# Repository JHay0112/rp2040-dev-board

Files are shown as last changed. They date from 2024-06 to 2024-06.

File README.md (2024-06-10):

# RP2040 Dev. Board

This repository contains a development board design for the RP2040 loosely 
based around the Pi Pico. 

The goal of this design was to produce a development board for a common 
microcontroller for the purpose of demonstrating a simple PCB design. The 
design had to be breadboard compatible and use USB-C for programming. 

The designed board (as shown below) fulfills all of these requirements.

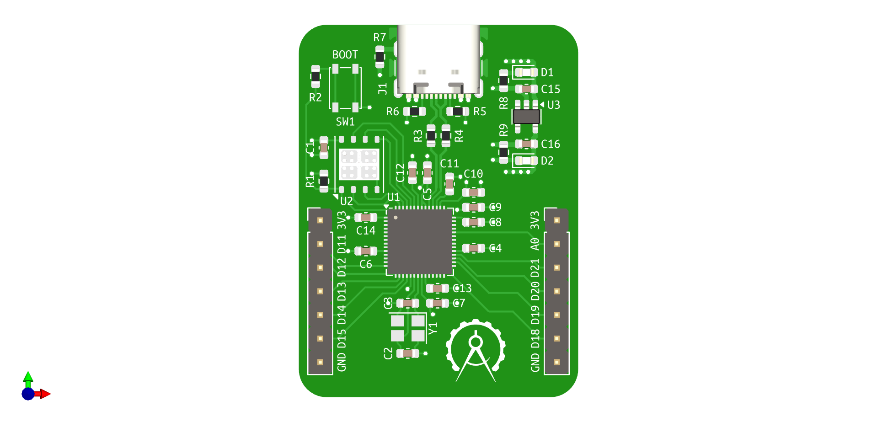
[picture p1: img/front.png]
Front View


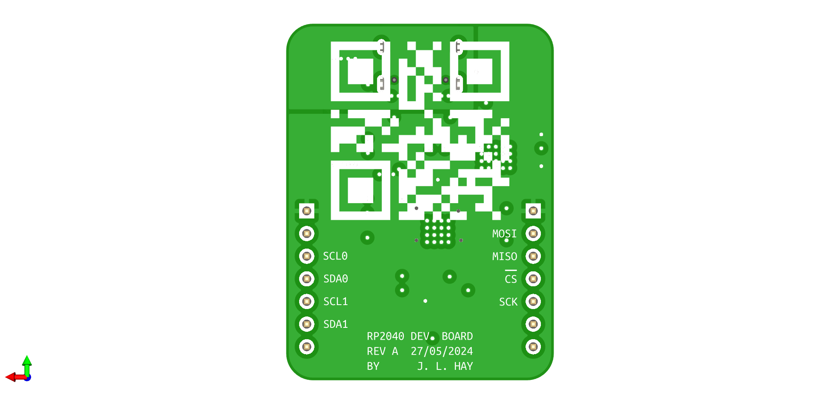
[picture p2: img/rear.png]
Rear View


The board was manufactured and assembled by JLCPCB, and used to blink an LED
to demonstrate it is in working condition (shown below).

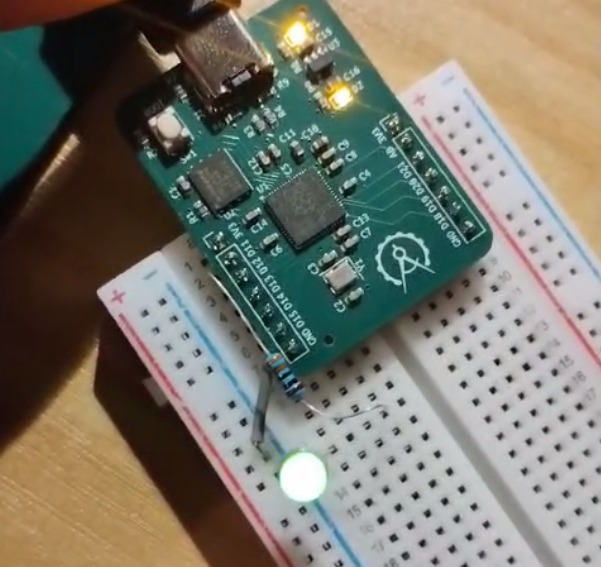
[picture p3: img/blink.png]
LED Blinking


The design of the board could be improved by increasing pin count and 
reducing the width of the PCB to allow more room for breadboarding around
the board.

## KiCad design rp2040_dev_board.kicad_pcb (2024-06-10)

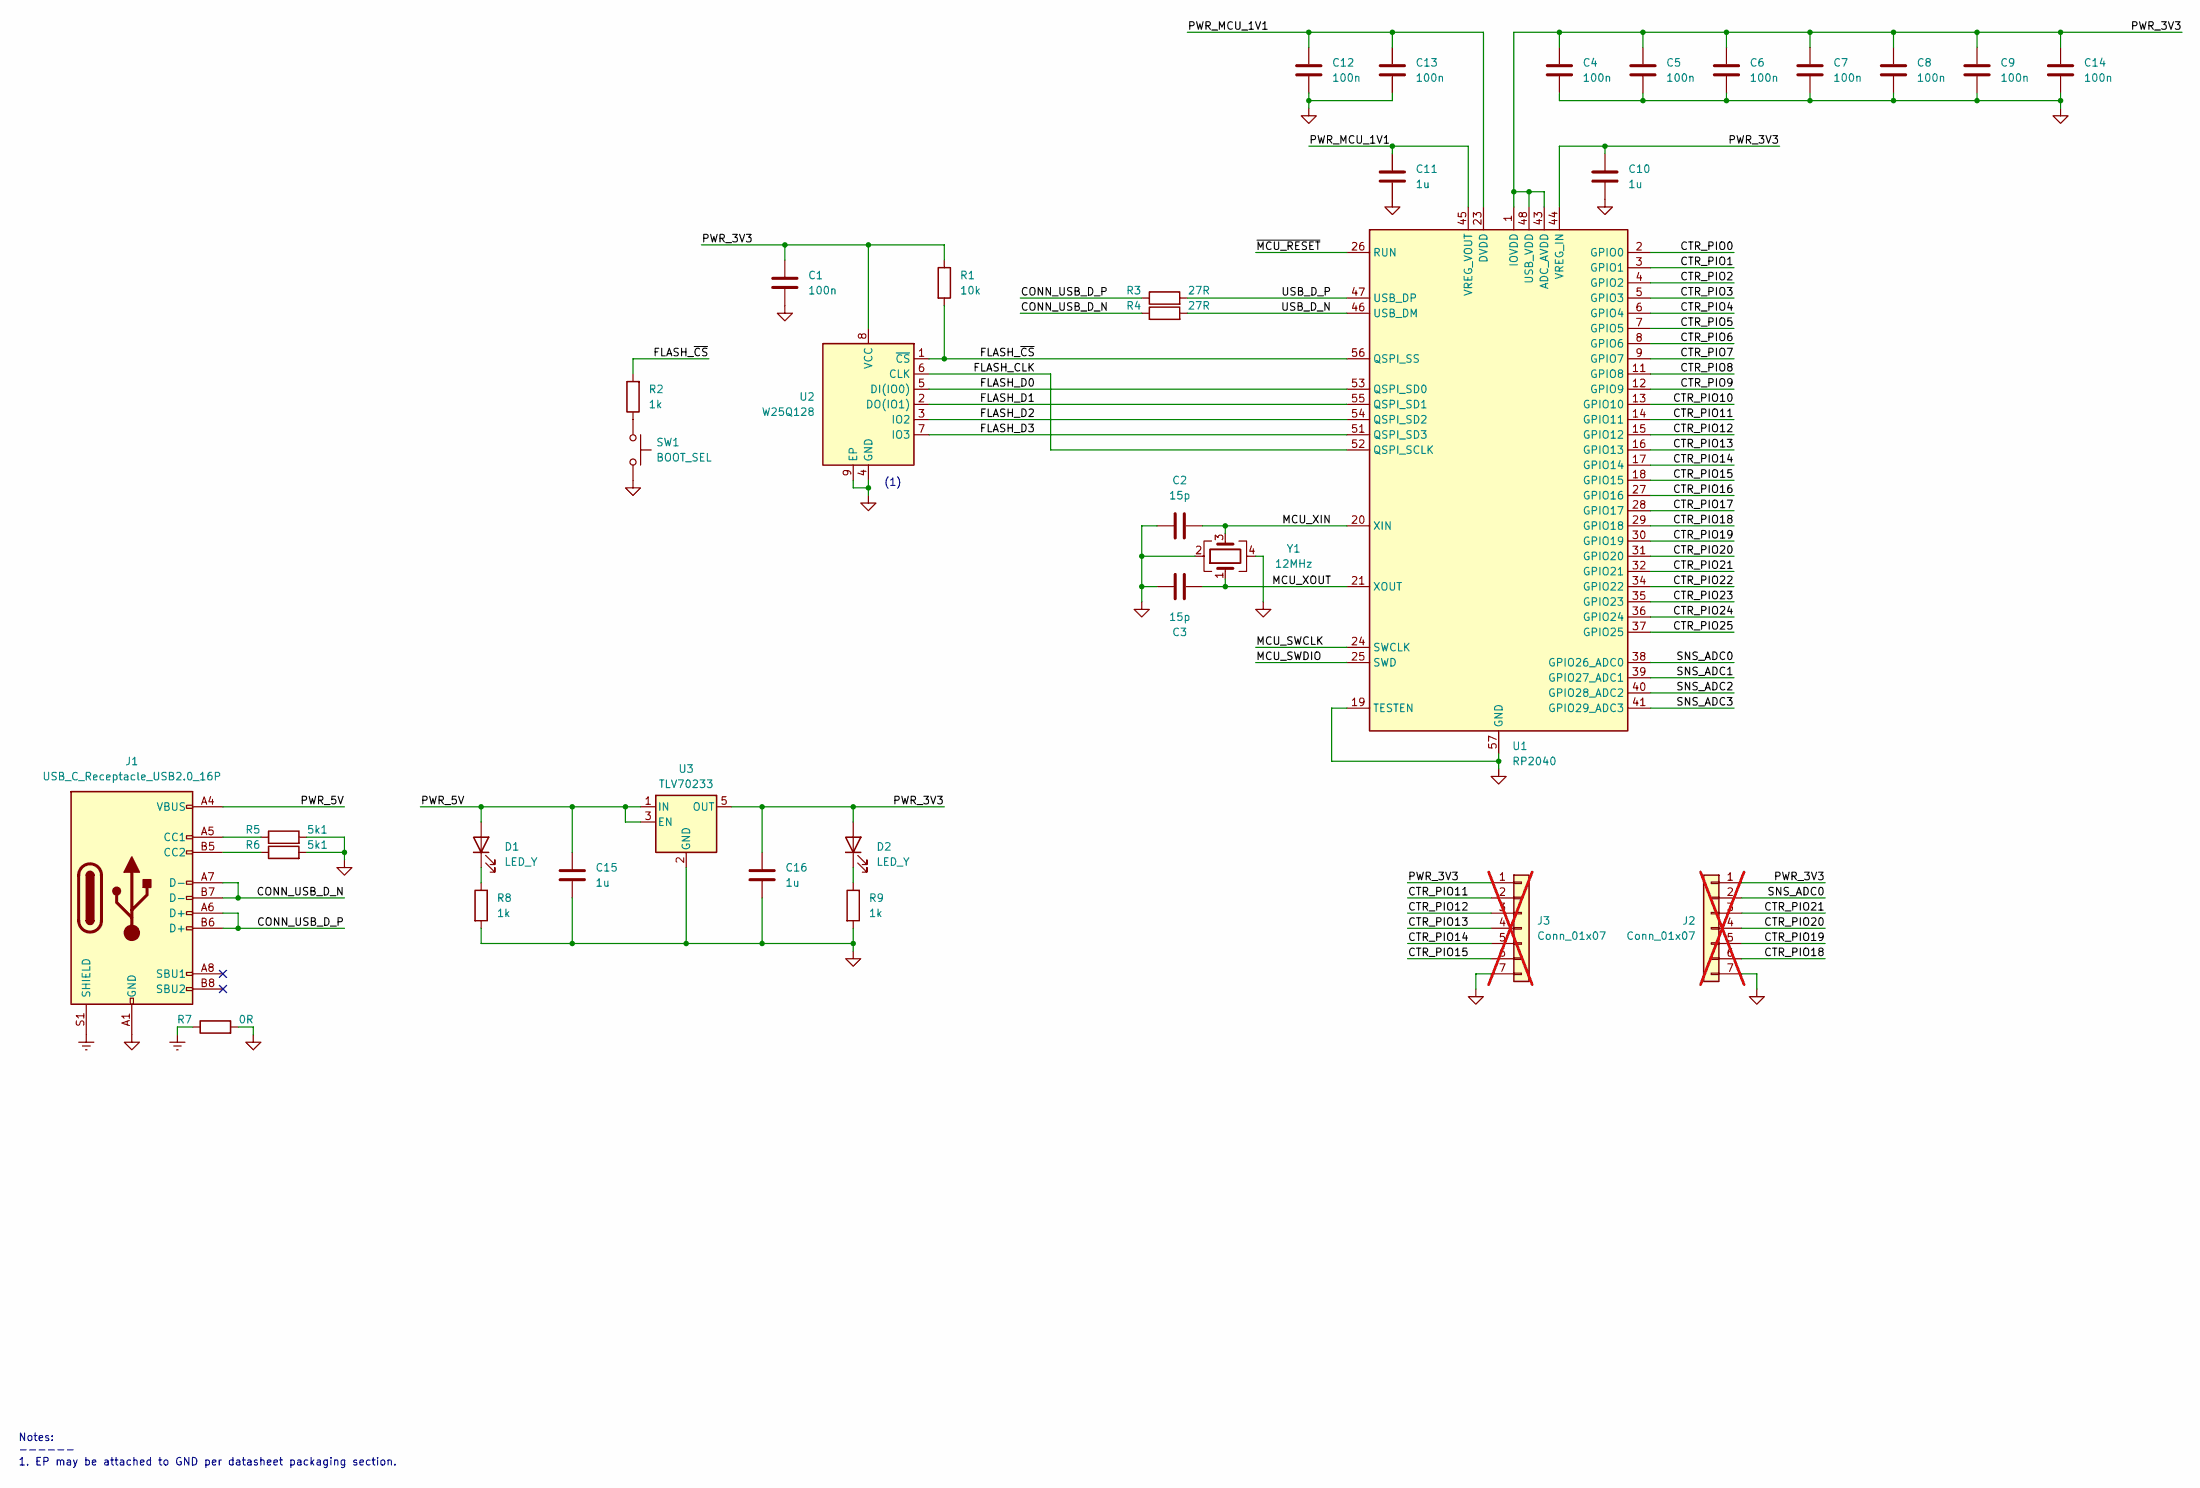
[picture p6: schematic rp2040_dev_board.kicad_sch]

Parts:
C1, C4, C5, C6, C7, C8, C9, C12, C13, C14: 100n; C_0603_1608Metric; Manufacturer PN CC0603KRX7R9BB104
C2, C3: 15p; C_0603_1608Metric; Manufacturer PN CL10C150JB8NNNC
C10, C11, C15, C16: 1u; C_0603_1608Metric; Manufacturer PN CC0603KRX7R9BB105
D1, D2: LED_Y; LED_0603_1608Metric; Manufacturer PN 19-213/Y2C-CQ2R2L/3T(CY)
J1: USB_C_Receptacle_USB2.0_16P; USB_C_Receptacle_GCT_USB4105-xx-A_16P_TopMnt_Horizontal; Manufacturer PN GT-USB-7004N
J2, J3: Conn_01x07; PinHeader_1x07_P2.54mm_Vertical; not fitted
R1: 10k; R_0603_1608Metric; Manufacturer PN 0603WAF1002T5E
R2, R8, R9: 1k; R_0603_1608Metric; Manufacturer PN 0603WAF1001T5E
R3, R4: 27R; R_0603_1608Metric; Manufacturer PN 0603WAF270JT5E
R5, R6: 5k1; R_0603_1608Metric; Manufacturer PN 0603WAF5101T5E
R7: 0R; R_0603_1608Metric; Manufacturer PN 0603WAF0000T5E
SW1: BOOT_SEL; SW_SPST_PTS810; Manufacturer PN TSA016A2518C
U1: RP2040; QFN-56-1EP_7x7mm_P0.4mm_EP3.2x3.2mm; Manufacturer PN RP2040
U2: W25Q128; WSON-8-1EP_6x5mm_P1.27mm_EP3.4x4.3mm; Manufacturer PN W25Q128JVPIQ
U3: TLV70233; SOT-23-5; Manufacturer PN TLV70233DBVR
Y1: 12MHz; Crystal_SMD_Abracon_ABM8AIG-4Pin_3.2x2.5mm; Manufacturer PN ABM8-272-T3

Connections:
/CONN_USB_D_N: J1.A7 (D-), J1.B7 (D-), R4.1
/CONN_USB_D_P: J1.A6 (D+), J1.B6 (D+), R3.1
/CTR_PIO0: U1.2 (GPIO0)
/CTR_PIO1: U1.3 (GPIO1)
/CTR_PIO2: U1.4 (GPIO2)
/CTR_PIO3: U1.5 (GPIO3)
/CTR_PIO4: U1.6 (GPIO4)
/CTR_PIO5: U1.7 (GPIO5)
/CTR_PIO6: U1.8 (GPIO6)
/CTR_PIO7: U1.9 (GPIO7)
/CTR_PIO8: U1.11 (GPIO8)
/CTR_PIO9: U1.12 (GPIO9)
/CTR_PIO10: U1.13 (GPIO10)
/CTR_PIO11: J3.2, U1.14 (GPIO11)
/CTR_PIO12: J3.3, U1.15 (GPIO12)
/CTR_PIO13: J3.4, U1.16 (GPIO13)
/CTR_PIO14: J3.5, U1.17 (GPIO14)
/CTR_PIO15: J3.6, U1.18 (GPIO15)
/CTR_PIO16: U1.27 (GPIO16)
/CTR_PIO17: U1.28 (GPIO17)
/CTR_PIO18: J2.6, U1.29 (GPIO18)
/CTR_PIO19: J2.5, U1.30 (GPIO19)
/CTR_PIO20: J2.4, U1.31 (GPIO20)
/CTR_PIO21: J2.3, U1.32 (GPIO21)
/CTR_PIO22: U1.34 (GPIO22)
/CTR_PIO23: U1.35 (GPIO23)
/CTR_PIO24: U1.36 (GPIO24)
/CTR_PIO25: U1.37 (GPIO25)
/FLASH_CLK: U1.52 (QSPI_SCLK), U2.6 (CLK)
/FLASH_D0: U1.53 (QSPI_SD0), U2.5 (DI(IO0))
/FLASH_D1: U1.55 (QSPI_SD1), U2.2 (DO(IO1))
/FLASH_D2: U1.54 (QSPI_SD2), U2.3 (IO2)
/FLASH_D3: U1.51 (QSPI_SD3), U2.7 (IO3)
/FLASH_~CS: R1.2, R2.2, U1.56 (QSPI_SS), U2.1 (~CS)
/MCU_SWCLK: U1.24 (SWCLK)
/MCU_SWDIO: U1.25 (SWD)
/MCU_XIN: C2.2, U1.20 (XIN), Y1.3
/MCU_XOUT: C3.2, U1.21 (XOUT), Y1.1
/PWR_3V3: C1.1, C4.1, C5.1, C6.1, C7.1, C8.1, C9.1, C10.1, C14.1, C16.1, D2.2 (A), J2.1, J3.1, R1.1, U1.1 (IOVDD), U1.10 (IOVDD), U1.22 (IOVDD), U1.33 (IOVDD), U1.42 (IOVDD), U1.43 (ADC_AVDD), U1.44 (VREG_IN), U1.48 (USB_VDD), U1.49 (IOVDD), U2.8 (VCC), U3.5 (OUT)
/PWR_5V: C15.1, D1.2 (A), J1.A4 (VBUS), J1.A9 (VBUS), J1.B4 (VBUS), J1.B9 (VBUS), U3.1 (IN), U3.3 (EN)
/PWR_MCU_1V1: C11.1, C12.1, C13.1, U1.23 (DVDD), U1.45 (VREG_VOUT), U1.50 (DVDD)
/SNS_ADC0: J2.2, U1.38 (GPIO26_ADC0)
/SNS_ADC1: U1.39 (GPIO27_ADC1)
/SNS_ADC2: U1.40 (GPIO28_ADC2)
/SNS_ADC3: U1.41 (GPIO29_ADC3)
/USB_D_N: R4.2, U1.46 (USB_DM)
/USB_D_P: R3.2, U1.47 (USB_DP)
/~MCU_RESET: U1.26 (RUN)
Earth: J1.S1 (SHIELD), R7.1
GND: C1.2, C2.1, C3.1, C4.2, C5.2, C6.2, C7.2, C8.2, C9.2, C10.2, C11.2, C12.2, C13.2, C14.2, C15.2, C16.2, J1.A1 (GND), J1.A12 (GND), J1.B1 (GND), J1.B12 (GND), J2.7, J3.7, R5.2, R6.2, R7.2, R8.2, R9.2, SW1.2, U1.19 (TESTEN), U1.57 (GND), U2.4 (GND), U2.9 (EP), U3.2 (GND), Y1.2, Y1.4
unnamed: D1.1 (K), R8.1
unnamed: D2.1 (K), R9.1
unnamed: J1.A5 (CC1), R5.1
unnamed: J1.B5 (CC2), R6.1
unnamed: R2.1, SW1.1

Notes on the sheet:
Notes: ------ 1. EP may be attached to GND per datasheet packaging section.
(1)

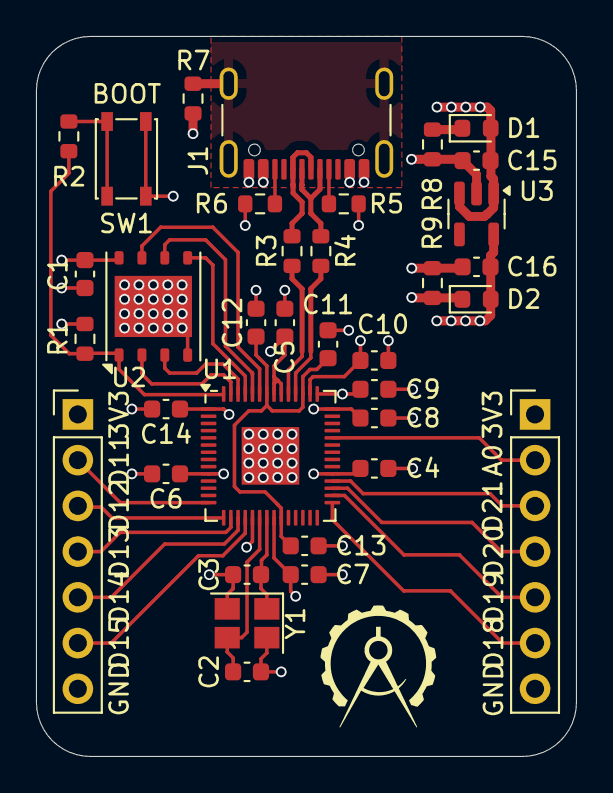
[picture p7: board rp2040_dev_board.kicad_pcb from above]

Board: 4 copper layers, 30.0 x 40.0 mm, 35 parts (0 on the bottom side), 32 nets.
